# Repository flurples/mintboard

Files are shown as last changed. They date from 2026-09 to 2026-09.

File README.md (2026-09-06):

# mintboard
a 40% bluetooth keyboard built into an altoids tin


build video: https://youtu.be/VZ1lAV-ThZo

## you will need
- an altoids tin
- a mintboard pcb (with diodes and switches)
- 1x top and 1x bottom housings
- keycaps ( 32x 1u, 2x 1.25u, 4x 1.5u, 2x 1.75u, 1x 4u)
- a nice!nano
- a small battery (I used a [301230](https://typeractive.xyz/products/lithium-battery-110mah?_pos=1&_sid=1f1b588b2&_ss=r) 110 mah lithium battery from typeractive)
- a [OS202011MA0QN1](https://www.digikey.com/en/products/detail/c-k/OS202011MA0QN1/1981434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) or equivalent power switch
- 4x m2 screws
- double sided tape
- a dremel or something to cut the altoids tin with

## notes
- pcb production files can be found in mintboard/pcb/production
- bom files were created for jlcpcb's parts library in 2023; double check correct components before ordering
- use the provided .uf2 file to flash the nice!nano, or build your own firmware if you want. the zmk build files were made for an older version of zmk so they will likely not work without some modification.

## disclaimer
I do not sell any products, and I am not affiliated with any vendors who claim to sell my designs. if you choose to support these vendors, I am not responsible for any issues you may encounter with them.

## gallery




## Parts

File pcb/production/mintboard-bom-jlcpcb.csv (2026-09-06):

Comment | Designator | Footprint | LCSC Part Number
D_Small | D1,D2,D3,D4,D5,D6,D7,D8,D9,D10,D11,D12,D13,D14,D15,D16,D17,D18,D19,D20,D21,D22,D23,D24,D25,D26,D27,D28,D29,D30,D31,D32,D33,D34,D35,D36,D37,D38,D39,D40,D41 | Diode_SMD:D_SOD-123 | C81598
PTS_647_SM38_SMTR2_LFS | S1,S2,S3,S4,S5,S6,S7,S8,S9,S10,S11,S12,S13,S14,S15,S16,S17,S18,S19,S20,S21,S22,S23,S24,S25,S26,S27,S28,S29,S30,S31,S32,S33,S34,S35,S36,S37,S38,S39,S40,S41 | button1:SW_PTS_647_SM38_SMTR2_LFS_1133 | C2689502

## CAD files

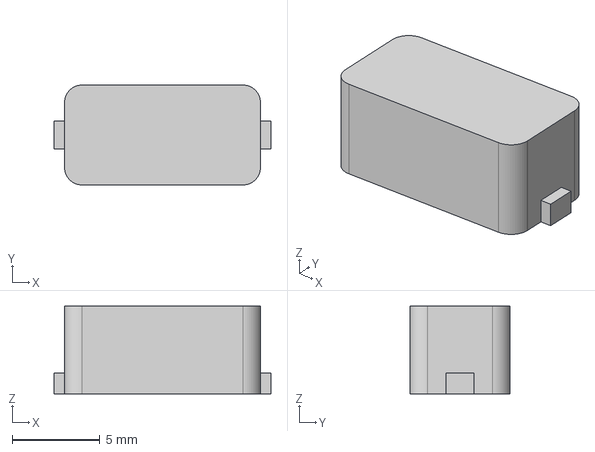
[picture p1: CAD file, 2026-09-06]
step/kecap-1.75u.step
12.4 x 5.70 x 5.00 mm

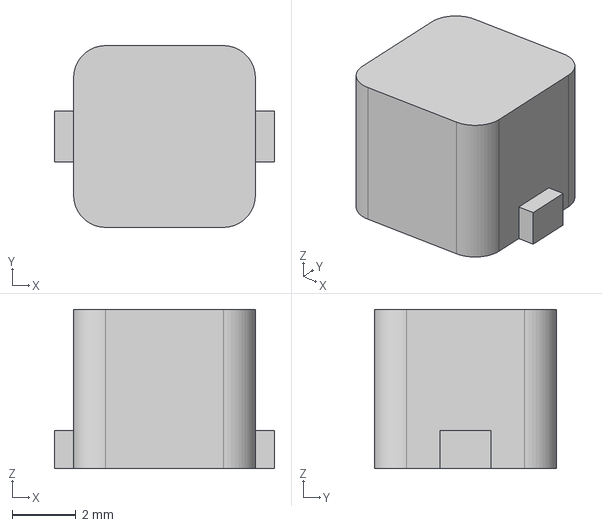
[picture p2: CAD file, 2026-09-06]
step/keycap-1u.step
6.90 x 5.70 x 5.00 mm

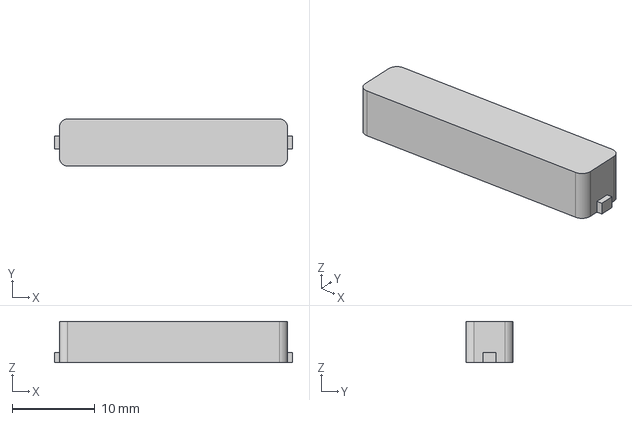
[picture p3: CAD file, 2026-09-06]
step/keycap-4u.step
28.8 x 5.70 x 5.00 mm

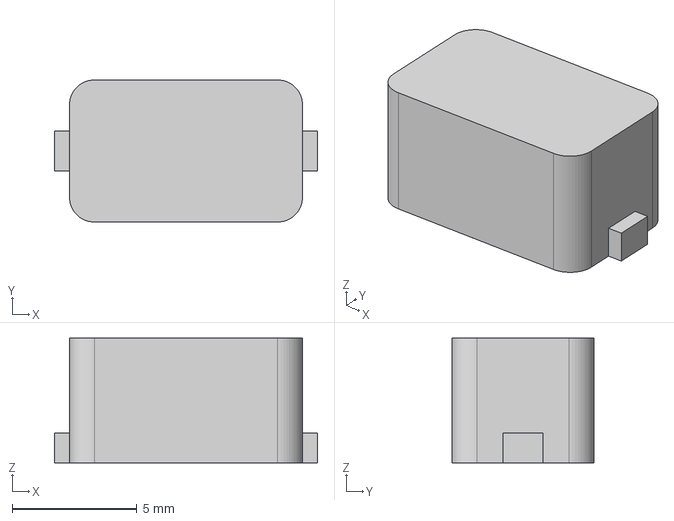
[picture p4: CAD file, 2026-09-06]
step/keycap-1.5u.step
10.6 x 5.70 x 5.00 mm

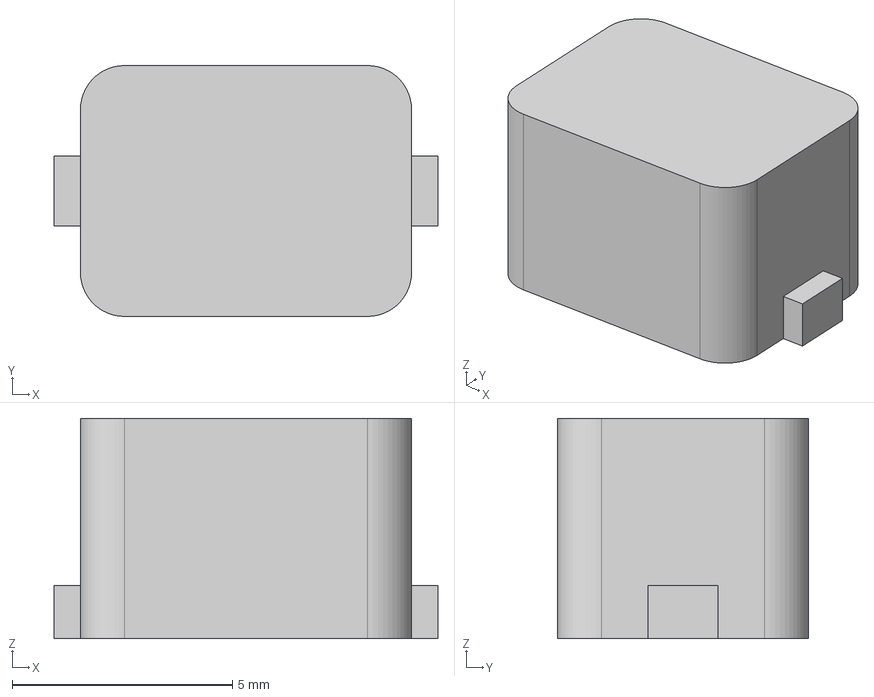
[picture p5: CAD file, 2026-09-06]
step/keycap-1.25u.step
8.73 x 5.70 x 5.00 mm

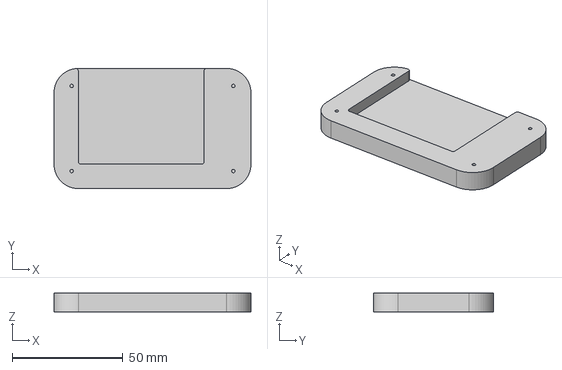
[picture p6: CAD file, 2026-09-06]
step/bottom.step
88.8 x 54.2 x 8.40 mm

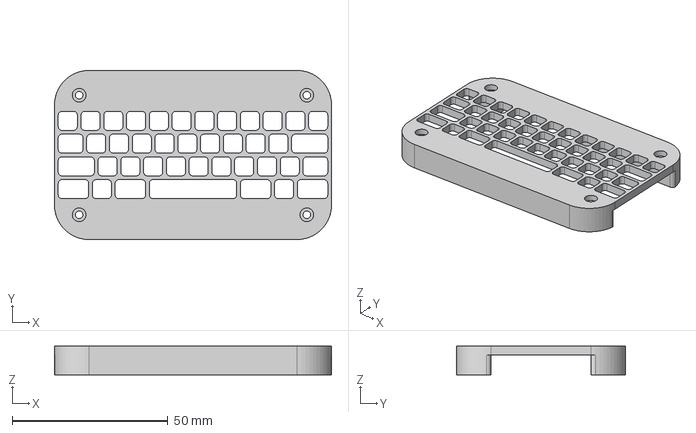
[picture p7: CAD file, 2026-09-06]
step/top.step
88.8 x 54.2 x 9.20 mm

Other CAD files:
stl/keycap-1.75u.stl
stl/bottom.stl
stl/keycap-1.25u.stl
stl/keycap-1.5u.stl
stl/keycap-1u.stl
stl/keycap-4u.stl
stl/top.stl

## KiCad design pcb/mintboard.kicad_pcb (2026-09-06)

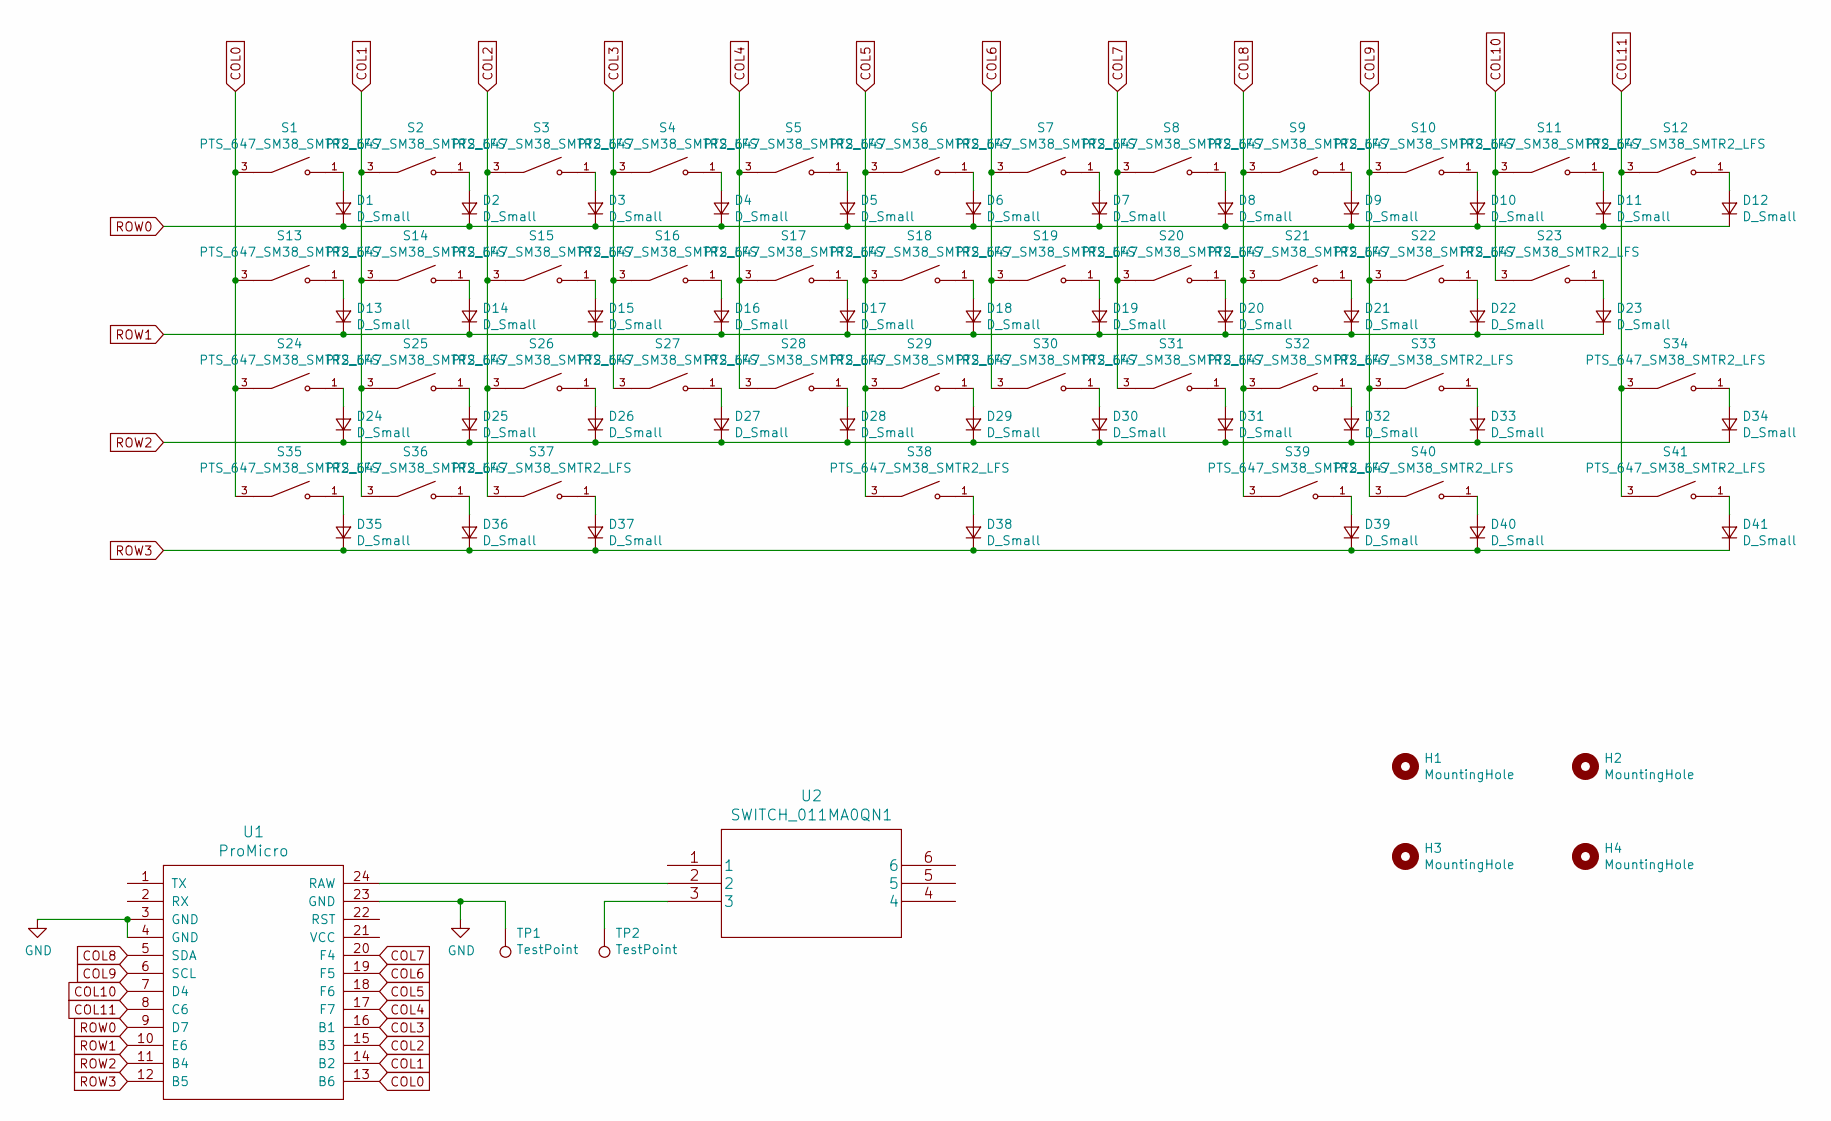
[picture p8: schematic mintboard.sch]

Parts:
D1, D2, D3, D4, D5, D6, D7, D8, D9, D10, D11, D12, D13, D14, D15, D16, D17, D18, D19, D20, D21, D22, D23, D24, D25, D26, D27, D28, D29, D30, D31, D32, D33, D34, D35, D36, D37, D38, D39, D40, D41: D_Small; D_SOD-123
H1, H2, H3, H4: MountingHole; MountingHole_2.5mm
S1, S2, S3, S4, S5, S6, S7, S8, S9, S10, S11, S12, S13, S14, S15, S16, S17, S18, S19, S20, S21, S22, S23, S24, S25, S26, S27, S28, S29, S30, S31, S32, S33, S34, S35, S36, S37, S38, S39, S40, S41: PTS_647_SM38_SMTR2_LFS; SW_PTS_647_SM38_SMTR2_LFS_1133; PARTREV 11 Jun 19
TP1, TP2: TestPoint; TestPoint_THTPad_D2.0mm_Drill1.0mm
U1: ProMicro; ProMicro-SMD
U2: SWITCH_011MA0QN1; OS202011MA0QN1

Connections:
COL0: S1.3, S13.3, S24.3, S35.3, U1.13 (B6)
COL1: S2.3, S14.3, S25.3, S36.3, U1.14 (B2)
COL2: S3.3, S15.3, S26.3, S37.3, U1.15 (B3)
COL3: S4.3, S16.3, S27.3, U1.16 (B1)
COL4: S5.3, S17.3, S28.3, U1.17 (F7)
COL5: S6.3, S18.3, S29.3, S38.3, U1.18 (F6)
COL6: S7.3, S19.3, S30.3, U1.19 (F5)
COL7: S8.3, S20.3, S31.3, U1.20 (F4)
COL8: S9.3, S21.3, S32.3, S39.3, U1.5 (SDA)
COL9: S10.3, S22.3, S33.3, S40.3, U1.6 (SCL)
COL10: S11.3, S23.3, U1.7 (D4)
COL11: S12.3, S34.3, S41.3, U1.8 (C6)
GND: TP1.1, U1.3 (GND), U1.4 (GND), U1.23 (GND)
unnamed: D1.2 (A), S1.1
unnamed: D2.2 (A), S2.1
unnamed: D3.2 (A), S3.1
unnamed: D4.2 (A), S4.1
unnamed: D5.2 (A), S5.1
unnamed: D6.2 (A), S6.1
unnamed: D7.2 (A), S7.1
unnamed: D8.2 (A), S8.1
unnamed: D9.2 (A), S9.1
unnamed: D10.2 (A), S10.1
unnamed: D11.2 (A), S11.1
unnamed: D12.2 (A), S12.1
unnamed: D13.2 (A), S13.1
unnamed: D14.2 (A), S14.1
unnamed: D15.2 (A), S15.1
unnamed: D16.2 (A), S16.1
unnamed: D17.2 (A), S17.1
unnamed: D18.2 (A), S18.1
unnamed: D19.2 (A), S19.1
unnamed: D20.2 (A), S20.1
unnamed: D21.2 (A), S21.1
unnamed: D22.2 (A), S22.1
unnamed: D23.2 (A), S23.1
unnamed: D24.2 (A), S24.1
unnamed: D25.2 (A), S25.1
unnamed: D26.2 (A), S26.1
unnamed: D27.2 (A), S27.1
unnamed: D28.2 (A), S28.1
unnamed: D29.2 (A), S29.1
unnamed: D30.2 (A), S30.1
unnamed: D31.2 (A), S31.1
unnamed: D32.2 (A), S32.1
unnamed: D33.2 (A), S33.1
unnamed: D34.2 (A), S34.1
unnamed: D35.2 (A), S35.1
unnamed: D36.2 (A), S36.1
unnamed: D37.2 (A), S37.1
unnamed: D38.2 (A), S38.1
unnamed: D39.2 (A), S39.1
unnamed: D40.2 (A), S40.1
unnamed: D41.2 (A), S41.1
unnamed: TP2.1, U2.3
unnamed: U1.24 (RAW), U2.2
ROW0: D1.1 (K), D2.1 (K), D3.1 (K), D4.1 (K), D5.1 (K), D6.1 (K), D7.1 (K), D8.1 (K), D9.1 (K), D10.1 (K), D11.1 (K), D12.1 (K), U1.9 (D7)
ROW1: D13.1 (K), D14.1 (K), D15.1 (K), D16.1 (K), D17.1 (K), D18.1 (K), D19.1 (K), D20.1 (K), D21.1 (K), D22.1 (K), D23.1 (K), U1.10 (E6)
ROW2: D24.1 (K), D25.1 (K), D26.1 (K), D27.1 (K), D28.1 (K), D29.1 (K), D30.1 (K), D31.1 (K), D32.1 (K), D33.1 (K), D34.1 (K), U1.11 (B4)
ROW3: D35.1 (K), D36.1 (K), D37.1 (K), D38.1 (K), D39.1 (K), D40.1 (K), D41.1 (K), U1.12 (B5)

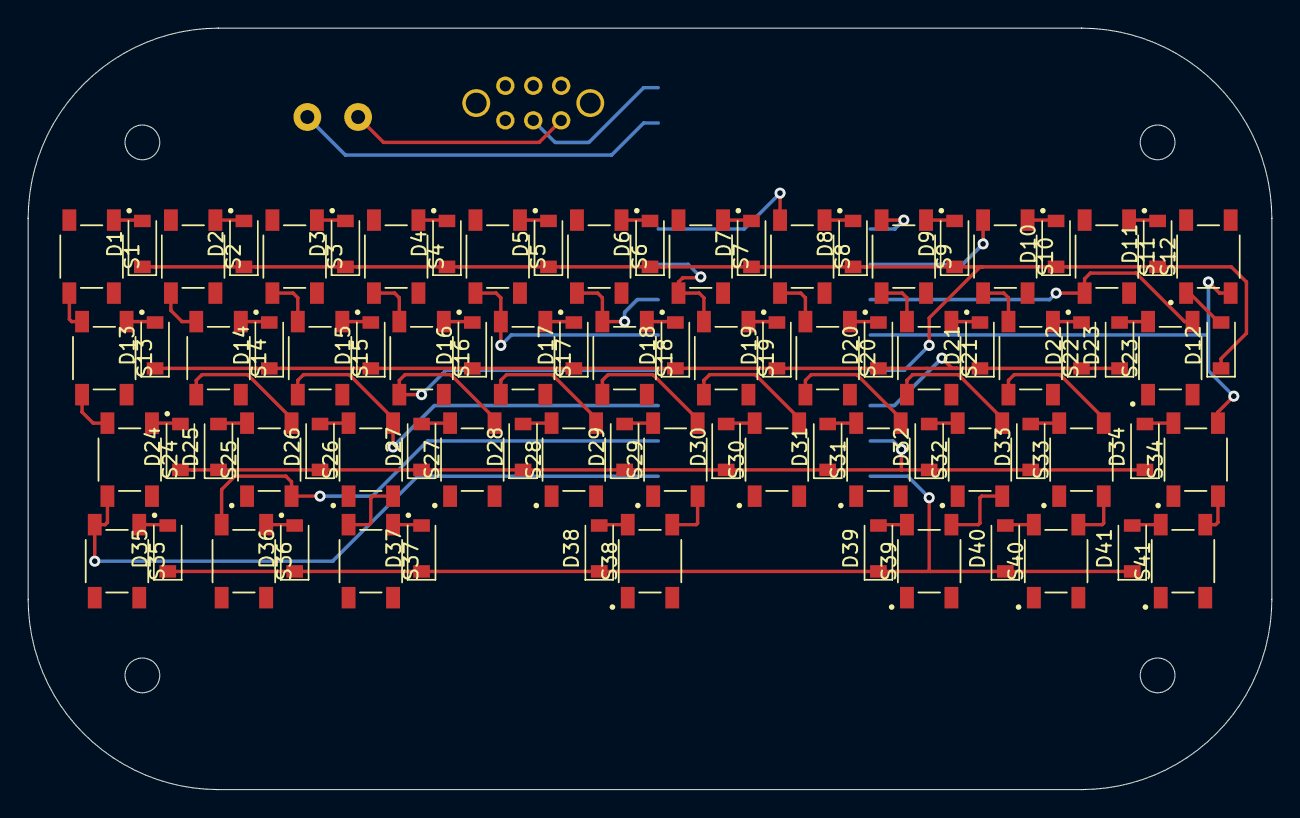
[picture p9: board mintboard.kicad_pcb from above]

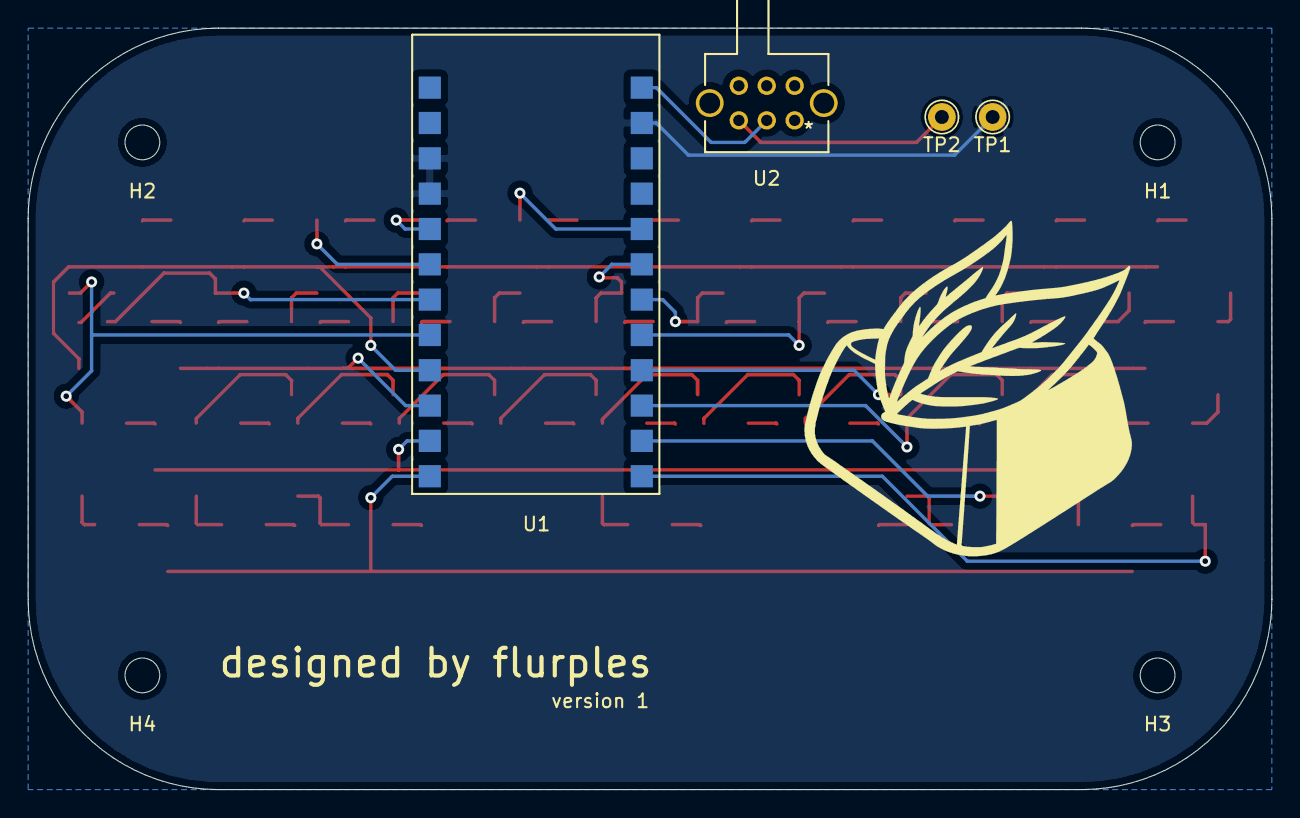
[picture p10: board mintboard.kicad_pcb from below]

Board: 2 copper layers, 89.4 x 54.8 mm, 90 parts (8 on the bottom side), 60 nets.

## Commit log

2026-09-06 add step and stl files
    [bottom.step, bottom.stl, kecap-1.75u.step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]
2026-09-06 add pcb files
    [mintboard-bom-jlcpcb.csv, mintboard.kicad_pcb, mintboard.sch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]

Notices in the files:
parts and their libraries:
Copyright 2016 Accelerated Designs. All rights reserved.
